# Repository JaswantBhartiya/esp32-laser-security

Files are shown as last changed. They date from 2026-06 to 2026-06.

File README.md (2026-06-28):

<div align="center">
  
Laser Security Sentinel Icon
  <br><br>
Typing Effect Headline

<br><br>

# 🛡️ ESP32 Multi-Bounce Laser Security System
<!-- Badges Section -->
<p align="center">
  
  
  
  
  
  
  
   
  
  
  
</p>

<h4>
    <a href="#demo">Demo</a>&nbsp;&nbsp;&nbsp;&nbsp;•&nbsp;&nbsp;&nbsp;&nbsp;
    <a href="#hardware">Hardware Design</a>&nbsp;&nbsp;&nbsp;&nbsp;•&nbsp;&nbsp;&nbsp;&nbsp;
    <a href="#mechanical">Mechanical Shroud</a>&nbsp;&nbsp;&nbsp;&nbsp;•&nbsp;&nbsp;&nbsp;&nbsp;
    <a href="#firmware">Firmware & Calibration</a>&nbsp;&nbsp;&nbsp;&nbsp;•&nbsp;&nbsp;&nbsp;&nbsp;
    <a href="https://github.com/JaswantBhartiya" target="_blank">Contact</a>
</h4>
</div>

<br>

A professional, budget-friendly embedded security system built around a custom PCB and the ESP32 DevKit V1. This project utilizes an optical multi-bounce laser path bounced across real glass mirrors to form a tight perimeter grid, monitored dynamically by an onboard Light Dependent Resistor (LDR).

<br><br>

---

## <span id="demo">🚀</span> Key Features & Demo

* **Wireless Perimeter Design:** The laser operates on its own isolated battery across the room, eliminating long, messy signal lines back to the controller.
* **Multi-Bounce Path:** Supports $650\text{nm}$ red or $532\text{nm}$ green lasers, holding a sharp focal point through 4 to 5 mirror reflections.
* **Auto Ambient Calibration:** Samples room light on boot to calculate a dynamic trigger threshold, preventing false alarms from day to night.
* **Dual-State LED Status:** Uses a Red-Green LED array (**Green** for Armed, **Red** for Tripped) mirrored on both the board and an external header.
* **Hardware Reset Button:** A debounced button on `GPIO 18` instantly clears the alarm, silences the buzzer, and re-arms the system.

<br>

### 🖥️ Live Web UI Dashboard
The system hosts a real-time responsive dashboard providing live telemetry, node statuses, and toggle configurations.

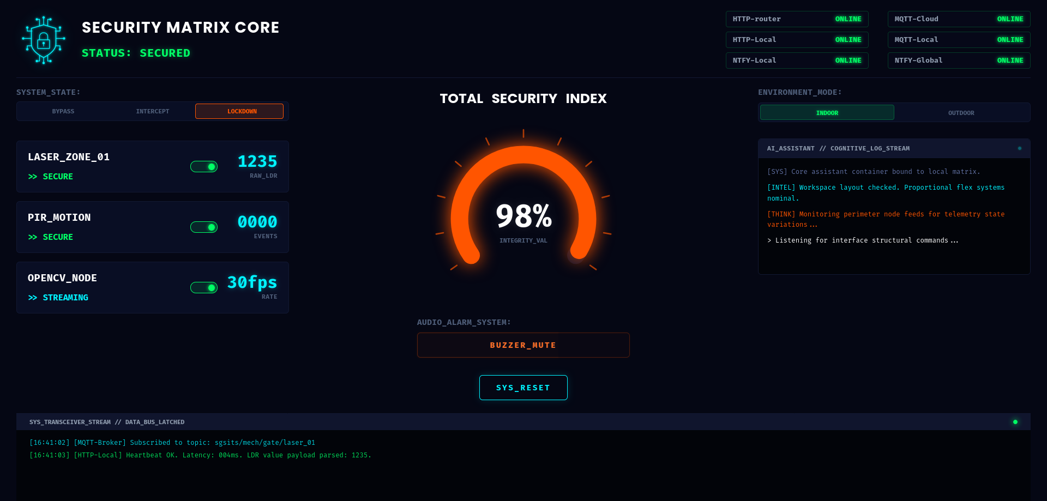
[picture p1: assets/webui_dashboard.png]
webui-dashboard


| Central Telemetry Instrumentation | Edge Sensor Matrix Nodes |
| :---: | :---: |
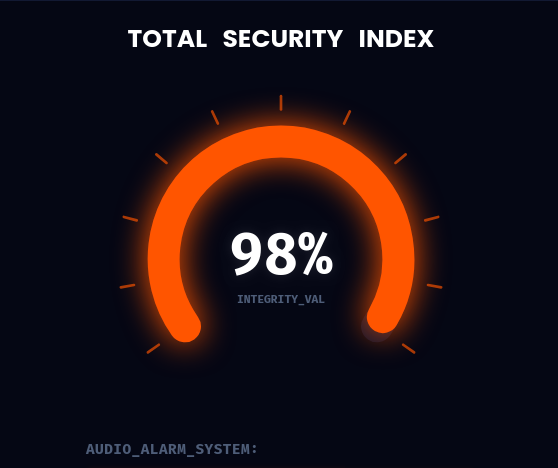
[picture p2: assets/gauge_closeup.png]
Radial Gauge
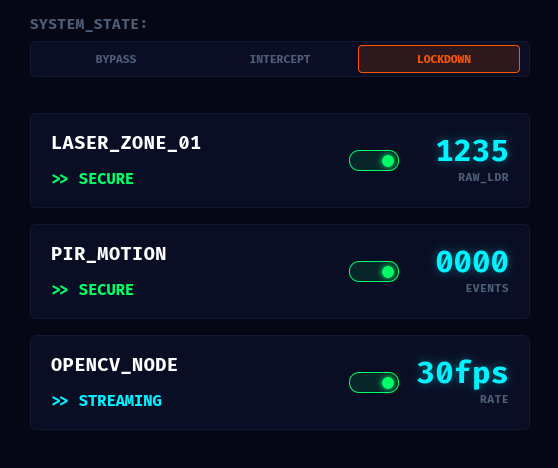
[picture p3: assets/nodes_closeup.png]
Sensor Status Toggles
|  |  |

#### 🌐 Robust 6-Way Connection Matrix
To guarantee fail-safe alerts and zero telemetry loss, the firmware maintains six independent network connections across local and global layers:
* **Wi-Fi Link Status:** Dual-channel monitoring covering your local gateway routing (`HTTP-Local`) and direct internet access (`HTTP-Router`).
* **MQTT Brokers:** Redundant pub/sub data streams routed concurrently to an offline network broker (`MQTT-Local`) and a remote cloud cluster (`MQTT-Cloud`).
* **Ntfy Push Alerts:** High-priority notification pipelines feeding instant breach logs via a self-hosted instance (`NTFY-Local`) and a global web server (`NTFY-Global`).

<br>

---

## <span id="hardware">🛠️</span> Hardware Design

### System Schematic
The circuit diagram maps out the ESP32 interface, sensor voltage dividers, and laser control lines for low-noise operation.

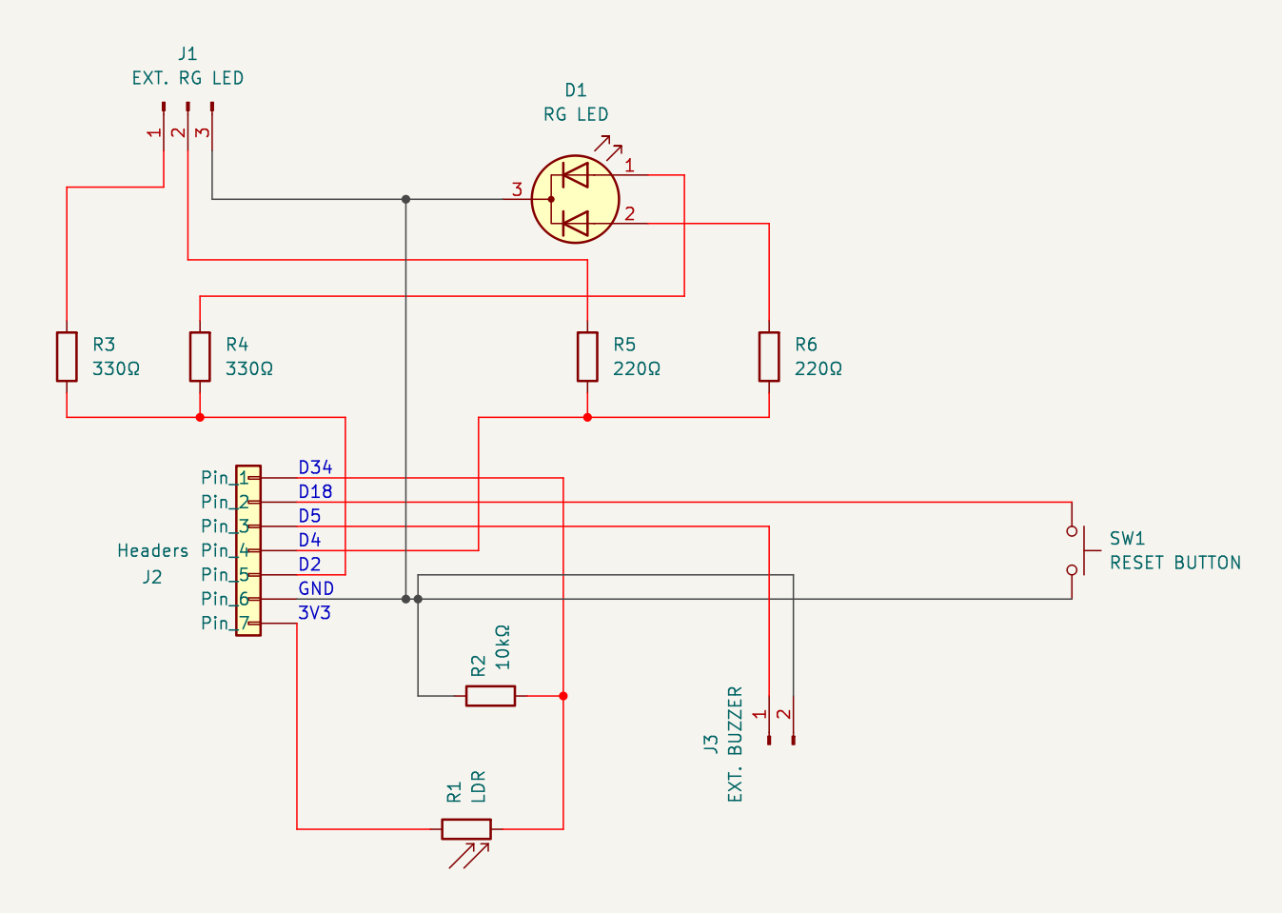
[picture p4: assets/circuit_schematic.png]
Circuit Schematic


<br>

### 📐 Electronics Layout (Raw KiCad PCB)
The custom board features a compact form factor, dedicated mounting holes, and clear silkscreen labeling.

| Front Layout | Back Layout |
| :---: | :---: |
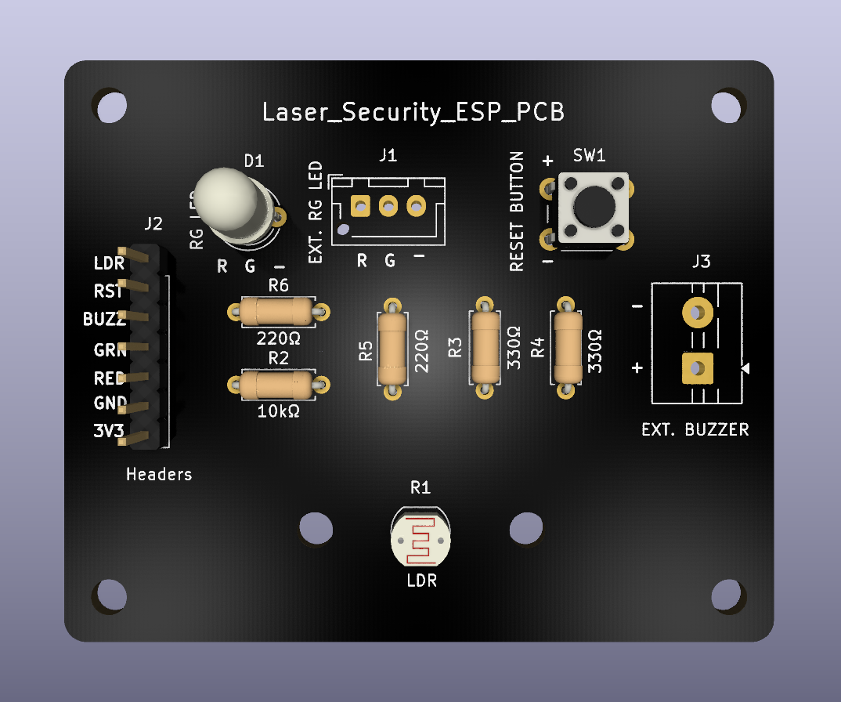
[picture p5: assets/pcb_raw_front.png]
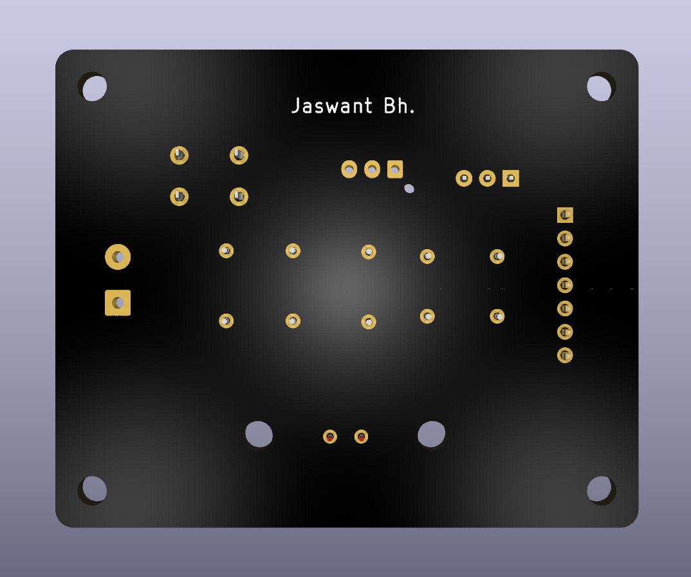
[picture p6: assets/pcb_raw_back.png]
|  |  |

<br>

### <span id="mechanical"></span>⚙️ Standalone Mechanical Mount
To achieve complete optical isolation and filter out ambient environmental light, a custom-molded mounting shroud was engineered.
<details> 
<summary><b>Click to Expand | Standalone Shroud Views</b></summary>

<br>

| Isometric View | Front View | Back View |
| :---: | :---: | :---: |
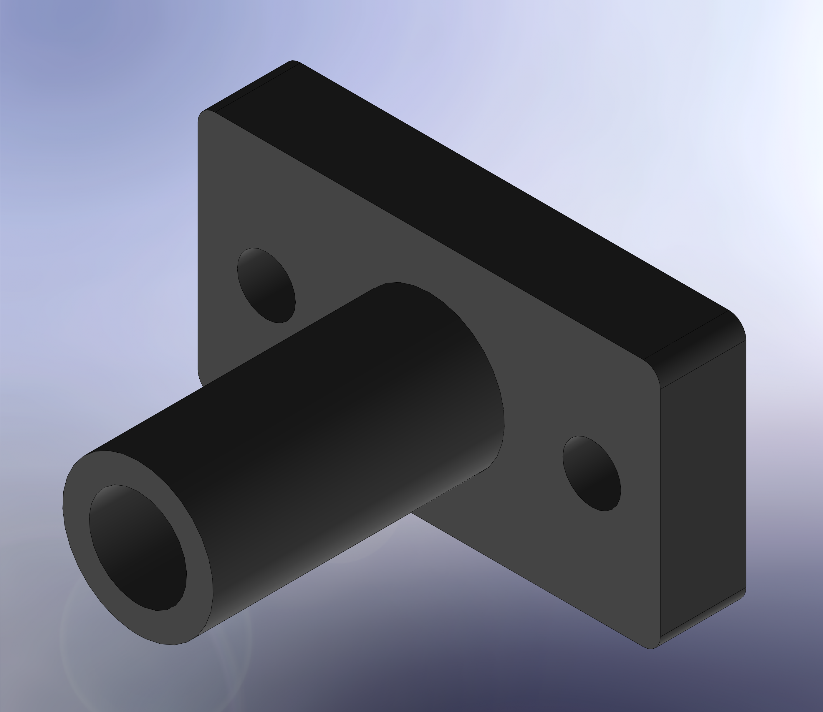
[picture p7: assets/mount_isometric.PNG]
Mount Front
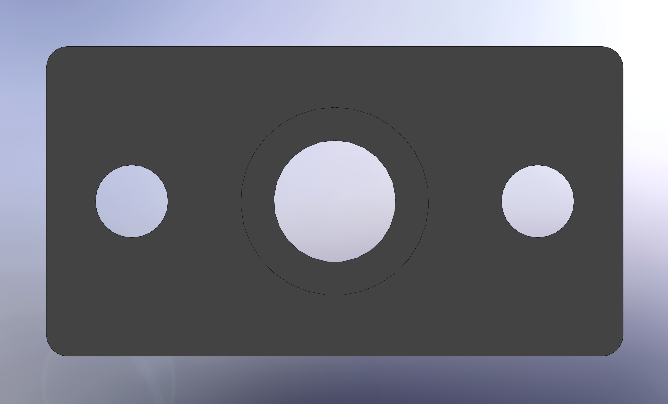
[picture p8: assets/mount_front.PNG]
Mount Top
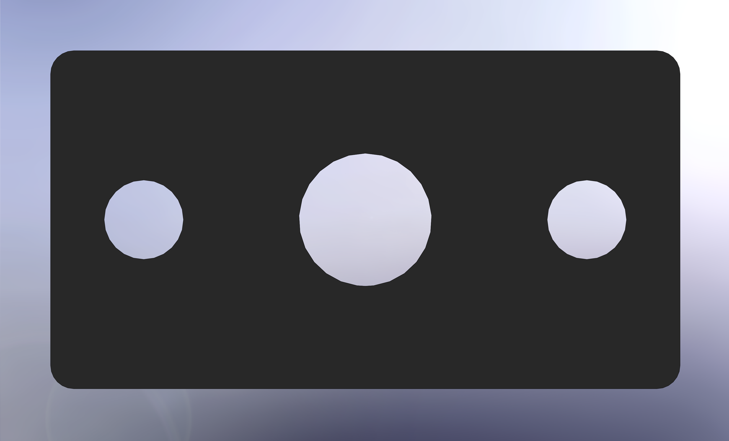
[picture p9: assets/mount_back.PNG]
Mount Bottom
|  |  |  |

#### 📐 Engineering Dimensions & Tolerances
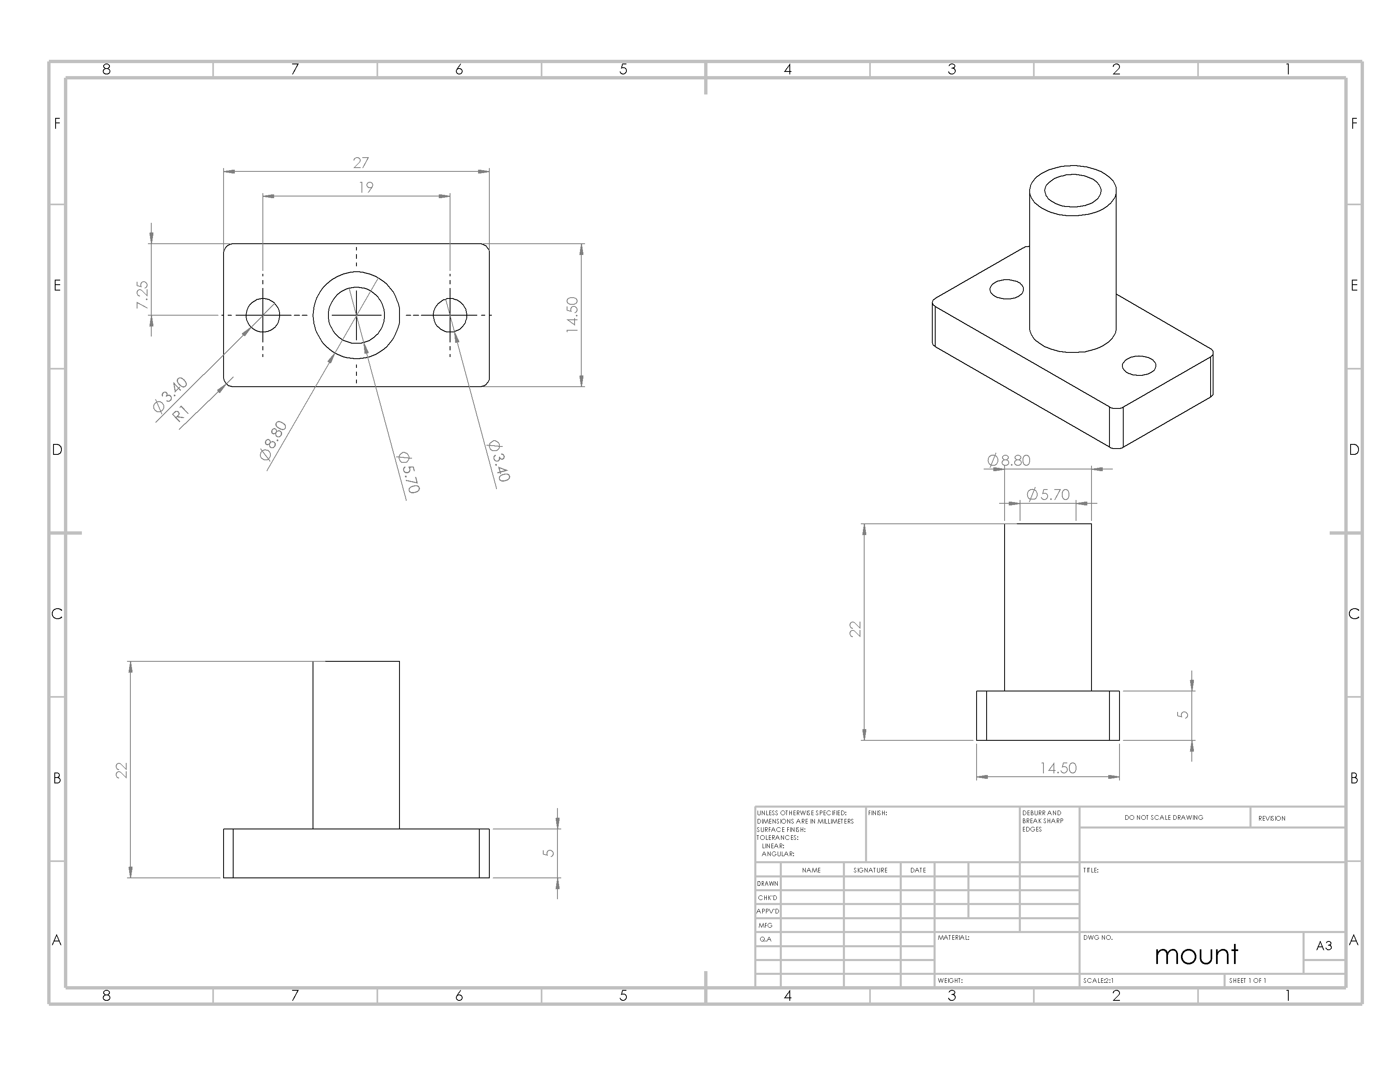
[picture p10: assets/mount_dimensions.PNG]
Mount Dimensions


**Design Specifications:**

* **Material:** Matte/Satin Dark Grey PLA (To absorb stray internal reflections)
* **Internal Diameter:** Uniform 5.7mm corridor (Provides a 0.5mm clearance cushion for hand-soldered LDR play and FDM printing shrinkage)
* **Fasteners:** Dual M3 clearance holes for flush mounting.

</details>

<br>

👉 **[Click here to view the interactive 3D Mount Model Natively on GitHub](./production/3d_printing/mount.STL)**

<br>

### 🤝 Fully Integrated Assembly
The combined views show the mechanical shroud assembly bolted directly onto the electronic control circuit board.

<div align="center">
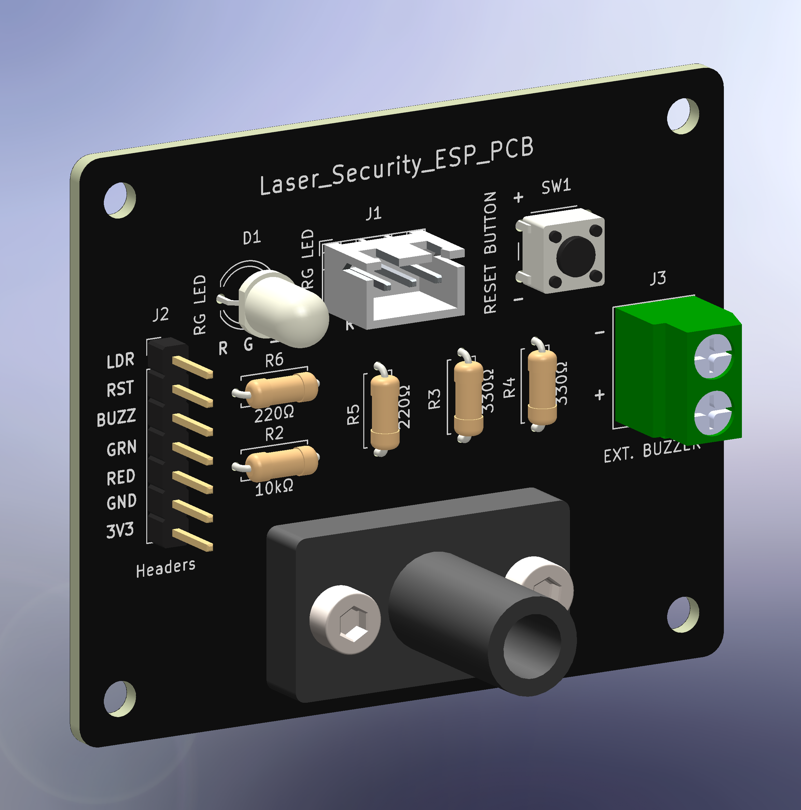
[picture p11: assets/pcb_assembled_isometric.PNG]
Integrated Isometric
       
</div>

<br>
       
| Assembly Top View | Assembly Solder Side View |
| :---: | :---: |
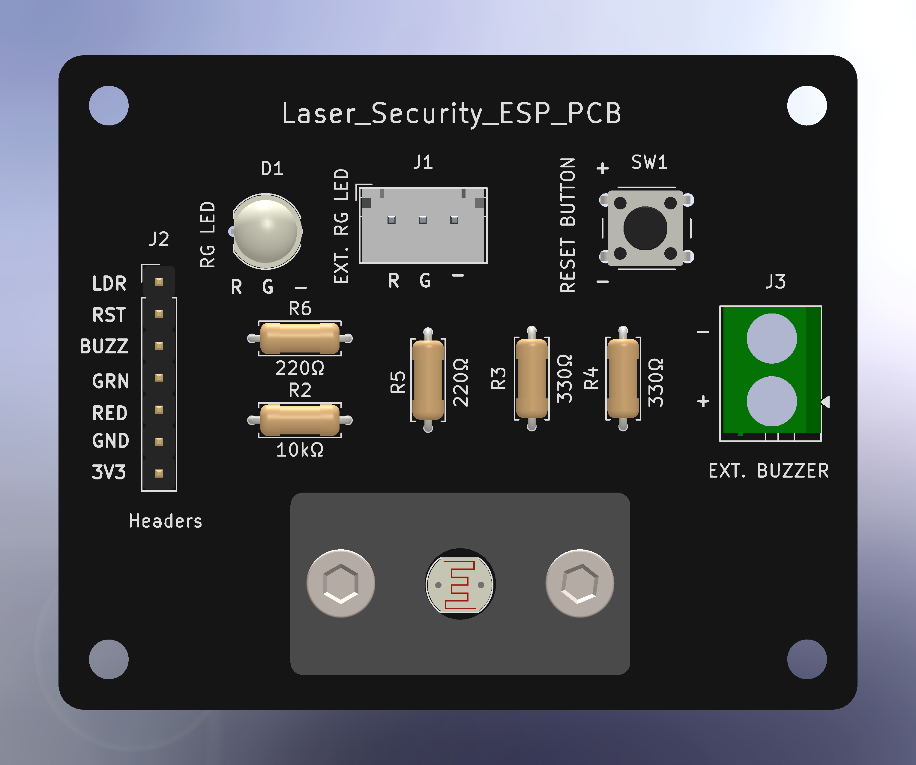
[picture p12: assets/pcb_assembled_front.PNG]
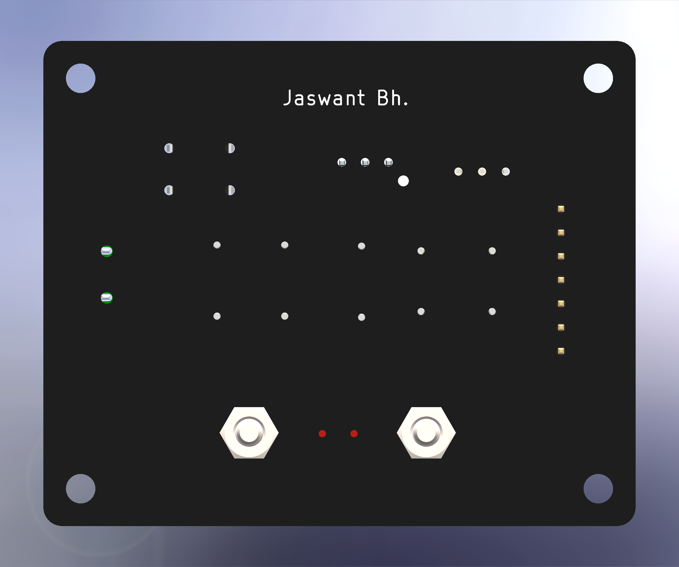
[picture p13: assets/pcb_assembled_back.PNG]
|  |  |

<br>

---

## 🔋 Power Setup

<details>
  
<summary><b>Click to Expand | Power Setup for two Paths</b></summary>

<br>

The system uses **two separate power paths** to stop electrical noise from the laser from messing with the ESP32 and sensors.

### ⚡ Path 1: ESP32 & Custom PCB
Powers the main controller and sensor board.

<div align="center">
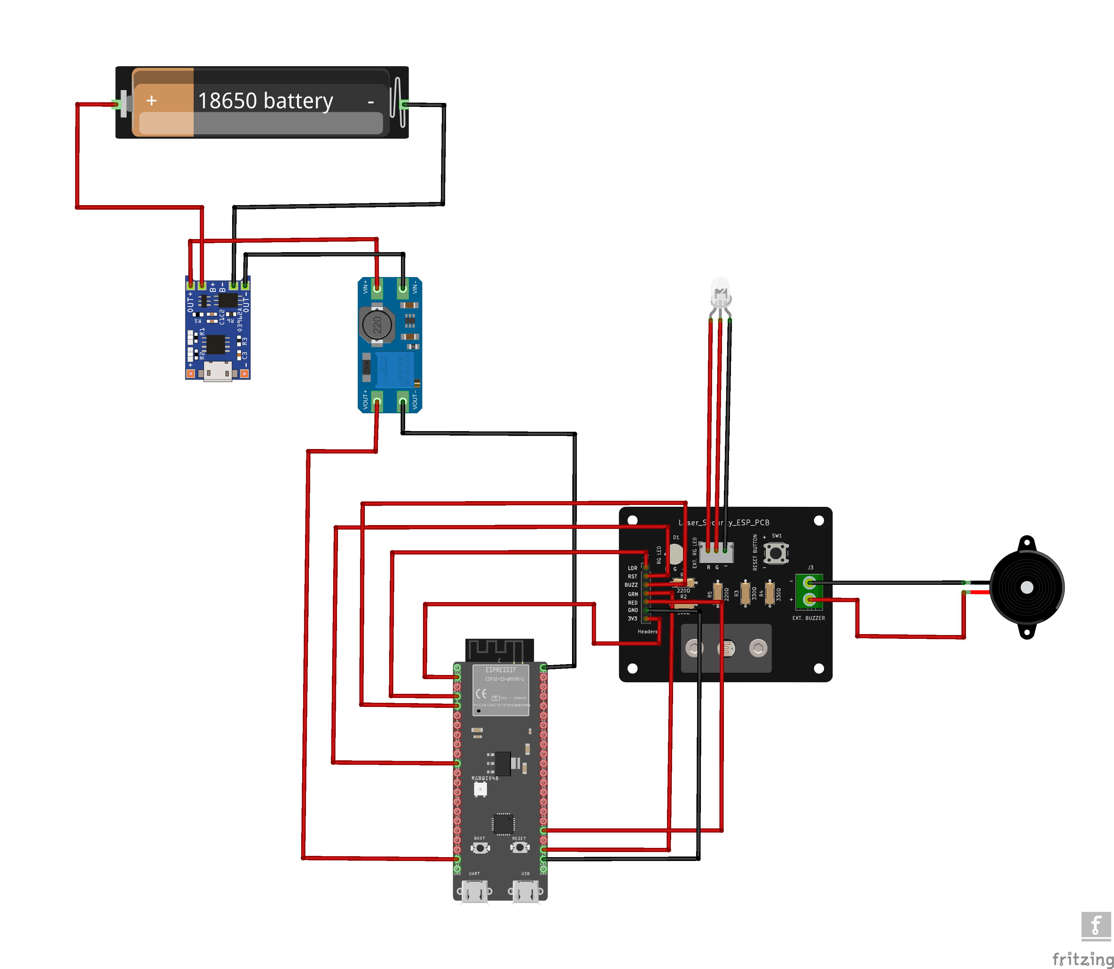
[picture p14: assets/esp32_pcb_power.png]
ESP32 Power Layout
       
</div>

<br>

* **Battery (18650)** ➔ **TP4056 Charger** (Safe charging)
* **TP4056 Output** ➔ **Boost Converter** (Steps up voltage)
* **Boost Converter (5V)** ➔ **ESP32 Pin (5V)** (Powers MCU)
* **ESP32 Pin (3.3V)** ➔ **Custom PCB (J2)** (Powers LDR & LED)

<br>

### 🔦 Path 2: Standalone Laser Transmitter Node
Powers the laser module independently with zero physical connection to the main board.

<div align="center">
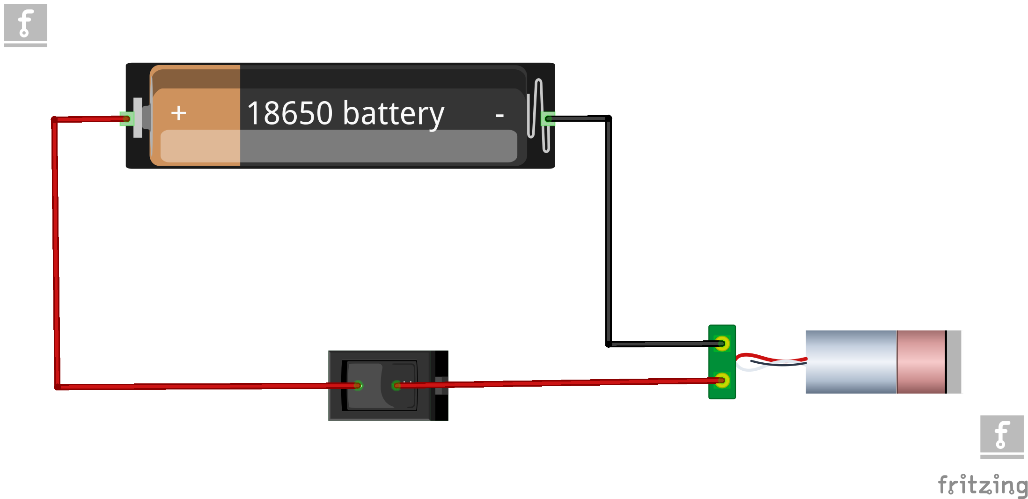
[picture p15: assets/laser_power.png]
Laser Power Layout
    
</div>

<br>

* **100% Isolated:** No shared wires or common ground loops with the ESP32-S3.
* **18650 Battery Powered:** Runs on its own 18650 cell (~3.7V) for maximum, long-lasting brightness.
* **Manual Switch Control:** Uses an inline rocker switch to completely cut power and save battery when off.

</details> 

<br>

---

## 📂 Repository Structure
``` yaml
      esp32-laser-security/
      ├── src/                             # 💻 Firmware Source Code (PlatformIO)
      │   ├── main.cpp                     #   └── Main security system logic
      │   └── testing/                     #   └── Isolated hardware testing scripts
      │       └── laser-connected-esp.cpp
      │
      ├── esp32-laser-security-pcb/        # 🛠️ KiCad Hardware Design Files
      │   ├── *.kicad_sch                  #   └── Circuit schematic
      │   └── *.kicad_pcb                  #   └── PCB routing layout
      │
      ├── production/                      # 📦 Manufacturing & 3D Printing Files
      │   ├── gerbers/                     #   └── PCB manufacturing files (Gerbers)
      │   ├── 3d_printing/                 #   └── 3D-printable mount shroud (.STL / .3MF)
      │   └── step_models/                 #   └── 3D CAD assembly model (.STEP)
      │
      ├── assets/                          # 🖼️ Documentation Media
      │   ├── circuit_schematic.png        #   └── Circuit diagram for README
      │   ├── pcb_raw_*.png/jpg            #   └── 3D images of unmounted PCB
      │   ├── mount_*.jpg                  #   └── 3D images of standalone plastic mount
      │   └── pcb_assembled_*.jpg          #   └── Photos of the final assembly
      │
      ├── platformio.ini                   # ⚙️ Project configuration & libraries
      └── README.md                        # 📖 Main project documentation guide
```
<br>

---

## 🛠️ Hardware Requirements

| Component | Quantity | Purpose |
| :--- | :--- | :--- |
| **ESP32-S3 DevKitC-1 N16R8** | 1 | Central processing unit & real-time monitoring engine |
| **SYD1230 650nm 5mW Red Laser Module** | 1 | Focusable transmitter node optimized for budget-friendly bouncing |
| **Light Dependent Resistor (LDR)** | 1 | High-sensitivity optical receiver |
| **SFM-27 Active Piezo Buzzer (Continuous Sound)** | 1 | 3–24V high-decibel audible indicator; allows the ESP32 to cleanly drive custom dual-frequency police siren sweeps without internal timing conflicts |
| **First-Surface Mirrors / HDD Platters** | 2–4 | Zero-ghosting high-reflectivity corner reflection nodes |
| **Metal Film Resistor (10 kΩ)** | 1 | Pull-down resistor for the analog voltage divider circuit |
| **Metal Film Resistor (330 Ω)** | 2 | Current-limiting protection resistors (e.g., for status LEDs) |
| **Metal Film Resistor (220 Ω)** | 2 | Current-limiting protection resistors (e.g., for buzzer power constraints) |
| **6x6x5mm Tactile Push Button Switch** | 1 | PCB-mount tactile switch for instant manual system reset or calibration |
| **7×1 Pin Male Berg Header (Straight, 10mm Height, 2.54mm Pitch)** | 1 | Breakout interface connector for peripheral GPIO programming/debugging pins |
| **XY126V-5.0-2P Green Screw Terminal Block (5mm Pitch, Through Hole)** | 1 | XINLAIYA 10A 300V power connector with wire protection for external main DC input |
| **3 Pin JST XH 2.5mm Top Entry Header (Straight Male & Female Pair)** | 1 | Polarity-keyed locking connector for secure LDR receiver wire routing |
| **Socket Head Cap Screw (M3x12)** | 2 | High-strength mechanical fasteners for enclosure or PCB corner mounting |
| **M3 Stainless Steel Hex Nut** | 2 | Matching rust-resistant hexagonal nuts to secure the M3 mounting screws safely |

<br>

---

## 🔌 Circuit Topology & Wiring

To achieve a clean optical baseline and prevent room lighting from flooding the sensor, the LDR must be housed inside an opaque, dark isolation tube pointed directly down the incoming laser path.

### Central Control Unit Pinout Mapping

```text
      +-----------------------------------------------------------------+
      |                    ESP32-S3 DevKitC-1 N16R8                     |
      +-----------------------------------------------------------------+
        | GPIO 4 (ADC) | <-------> Pin 1: LDR  (R1 Sensor Output Node)
        | GPIO 18       | <-------- Pin 2: RST  (Reset Push Button SW1)
        | GPIO 5        | --------> Pin 3: BUZZ (External Buzzer J3)
        | GPIO 19*      | --------> Pin 4: GRN  (Green LED Control Rail)
        | GPIO 21*      | --------> Pin 5: RED  (Red LED Control Rail)
        | GND           | --------> Pin 6: GND  (Common System Ground)
        | 3V3           | --------> Pin 7: 3V3  (System Power Input)

```
``` text
        +-----------------------------------------------------------------------------------+
        |                            EXTERNAL COMPONENT CONNECTIONS                         |
        +-----------------------------------------------------------------------------------+
        |                                                                                   |
        |  [ PCB Header J1 ] --------------------> Connects to EXTERNAL RG LED              |
        |     (EXT. RG LED)                         - Pin R: Red Indicator Anode            |
        |                                           - Pin G: Green Indicator Anode          |
        |                                           - Pin -: Common Ground Rail             |
        |                                                                                   |
        |  [ PCB Header J3 ] --------------------> Connects to EXTERNAL ACTIVE BUZZER       |
        |     (EXT. BUZZER)                         - Pin +: Positive Audio Signal Input    |
        |                                           - Pin -: Negative Ground Return         |
        |                                                                                   |
        +-----------------------------------------------------------------------------------+

```

### 3.3V Safe Voltage Divider Layout

```text
3V3 Rail -----[ LDR ]-----+-----> GPIO 34 (Analog Read Input)
                          |
                     [ 10kΩ Resistor ]
                          |
                         GND Rail
```
_Note: Powering the LDR network from the 3V3 rail protects the ESP32's 12-bit ADC pins from 5V over-voltage degradation._

<br>

---

## 💻 Software Configuration & Installation

This project is built using PlatformIO IDE inside VS Code for robust environment management and smaller, compiled binary footprints.
### Project Environment Configuration (platformio.ini)

```Ini, TOML

[env:esp32-s3-devkitc-1]
platform = espressif32
board = esp32-s3-devkitc-1
framework = arduino
monitor_speed = 115200

# Force the compiler to disable PSRAM tracking to prevent boot panics
build_flags = 
    -DBOARD_HAS_PSRAM=0
    -DARDUINO_USB_CDC_ON_BOOT=1

# Specify LittleFS partitioning layout
board_build.filesystem = littlefs

# Standard partition table for an 8MB Flash device (No PSRAM)
board_build.partitions = default_8MB.csv

lib_deps =
    esphome/ESPAsyncWebServer-esphome @ ^3.2.2
    knolleary/PubSubClient @ ^2.8

# Tell PlatformIO to compile everything in src, EXCEPT the testing folder
build_src_filter = +<*> -<testing/>

```
<br>

### Deployment Instructions

1. Clone this repository to your local workspace:
    ```Bash
    git clone https://github.com/JaswantBhartiya/esp32-laser-security.git
    ```
    
2. Open the project folder directly inside **Visual Studio Code** with the **PlatformIO** extension active.

3. Align your external laser node across your mirror grid so it hits the center of the LDR tube.

4. Click the **PlatformIO**: **Upload** arrow icon on the bottom status bar (or press (`Ctrl + Alt + U`) to compile and flash the firmware.

5. Open the **Serial Monitor** (`Ctrl + Alt + M`) at `115200` baud to watch the system run its initial calibration profiling.
<br><br>

---

## ⚙️ How System States Work

```text
  
           +------------------+
           | STATE_CALIBRATING| <-------- On Boot / User Reset
           +------------------+
                     |
                     v (Samples light & computes threshold)
           +------------------+
      +--->|   STATE_ARMED    |
      |    +------------------+
      |              |
      |              v (Beam broken for >50ms)
      |    +------------------+
      |    |  STATE_BREACHED  |
      |    +------------------+
      |              |
      +--------------+ (Reset Button Pressed)

```

* **Boot Calibration:** Samples the laser beam for 3 seconds to calculate a dynamic trigger threshold between direct laser light and ambient room light.
* **Active Guard:** Continuously samples the LDR. Requires the beam to be broken for over `50ms` to filter out false alarms from dust or bugs.
* **Breached Alert:** Plays a dual-tone siren sweep ($800\text{Hz}$ to $1300\text{Hz}$) on `GPIO 5` using non-blocking microsecond delays.
* **Hardware Reset:** Actively polls `GPIO 18`. Pressing the reset button instantly mutes the buzzer and recalibrates the system back to Armed mode.

<br>

---

## ⚙️ Calibration & Environment Tuning

### 🛠️ Quick Alignment Guide

1. **Align:** Aim the laser dot directly into the center of the LDR shroud.
2. **Calibrate:** Power on or reset the ESP32. Keep the laser path completely clear for the first **3 seconds**.
3. **Calculate:** The firmware auto-sets the trigger threshold using a simple median formula:

$$\text{Threshold} = \frac{\text{Laser Intensity} + \text{Ambient Light}}{2}$$

4. **Verify:** Block the beam with your hand to test that it instantly triggers the alarm.

<br>

### 🔍 Ambient Light Troubleshooting

| Issue | Root Cause | Quick Fix |
| :--- | :--- | :--- |
| **Instant alarm on boot** | Laser missed the LDR during calibration. | Re-align the laser and press the reset button to recalibrate. |
| **Beam broken, no alarm** | Side-glare or ambient room light is bleeding into the sensor. | Move away from windows or use a longer 3D-printed shroud to block ambient light. |
| **Siren flickers/jitters** | Laser dot is slightly misaligned or vibrating on the edge of the sensor. | Tighten your laser/mirror mounts to eliminate physical jitter. |

<br>

---

## 🚀 Hardware Evolution & Development
To see the complete multi-phase development timeline—including planned v2.0 hardware protection circuits, v3.0 wireless IoT feature tracking, and long-term mechanical upgrades—view the project's growth pipeline:

👉 **[View the Comprehensive Project Roadmap & Future Upgrades](./HARDWARE_ROADMAP.md)**

<br>

---

## 📄 License

This project is licensed under the MIT License - see the [`LICENSE`](./LICENSE) file for details.

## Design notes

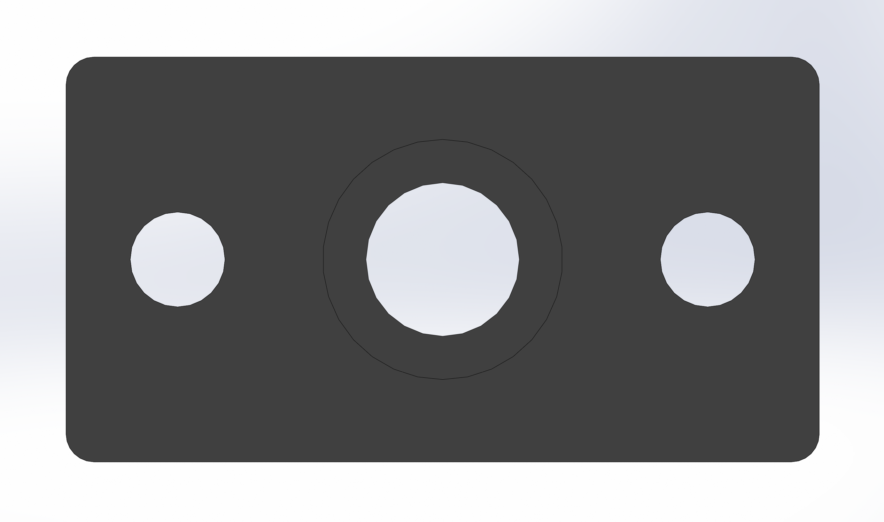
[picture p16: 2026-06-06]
assets/mount_top.PNG

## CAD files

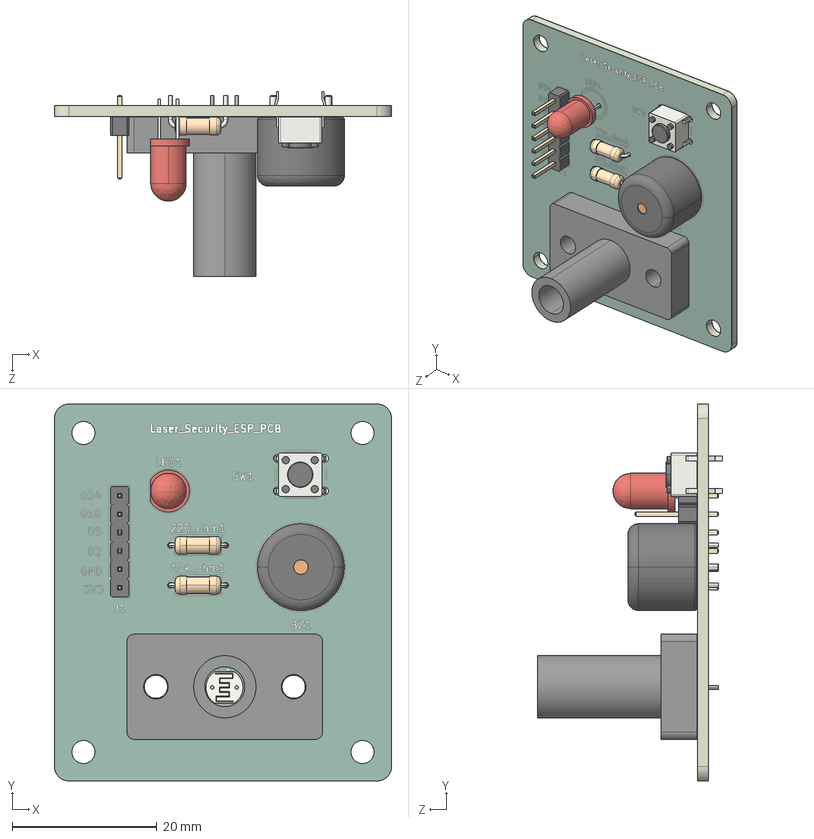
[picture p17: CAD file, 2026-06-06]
production/step_models/pcb_and_mount_assembly.STEP
46.5 x 52.0 x 25.5 mm
R_Axial_DIN0207_L63mm_D25mm_P762mm_Horizontal x 2
Buzzer_12x95RM76
PinHeader_1x06_P254mm_Vertical
R_LDR_5.1x4.3mm_P3.4mm_Vertical
LED_D5.0mm
SW_PUSH_6mm
esp32-laser-security_silkscreen
esp32-laser-security_soldermask
esp32-laser-security_soldermask_2
esp32-laser-security_PCB

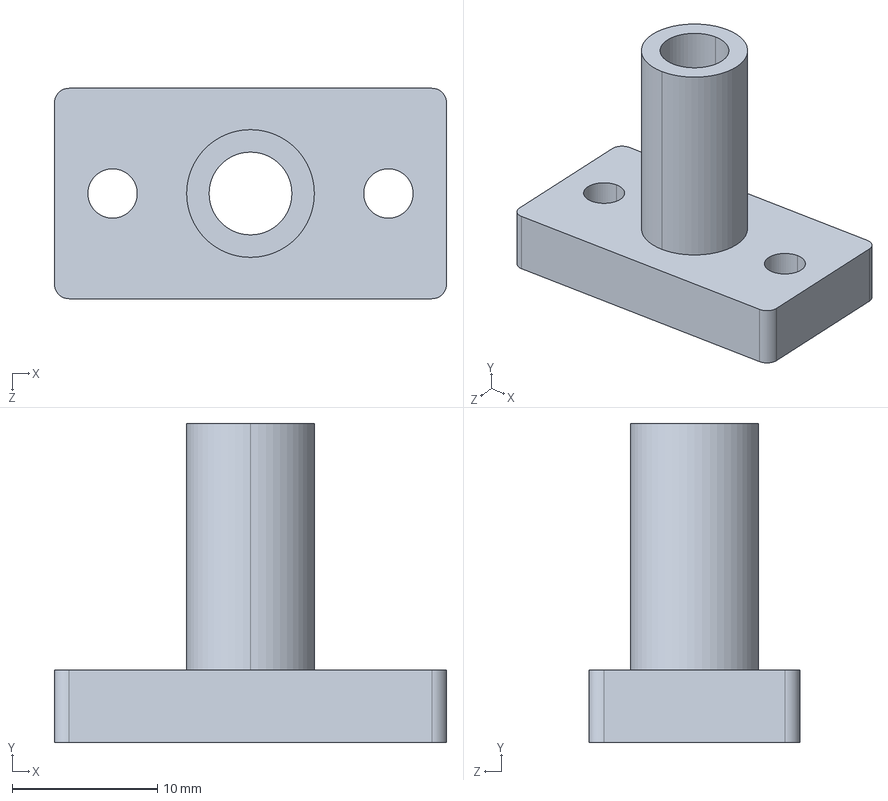
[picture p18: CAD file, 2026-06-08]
production/step_models/mount.STEP
27.0 x 22.0 x 14.5 mm

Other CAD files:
production/3d_printing/mount.STL

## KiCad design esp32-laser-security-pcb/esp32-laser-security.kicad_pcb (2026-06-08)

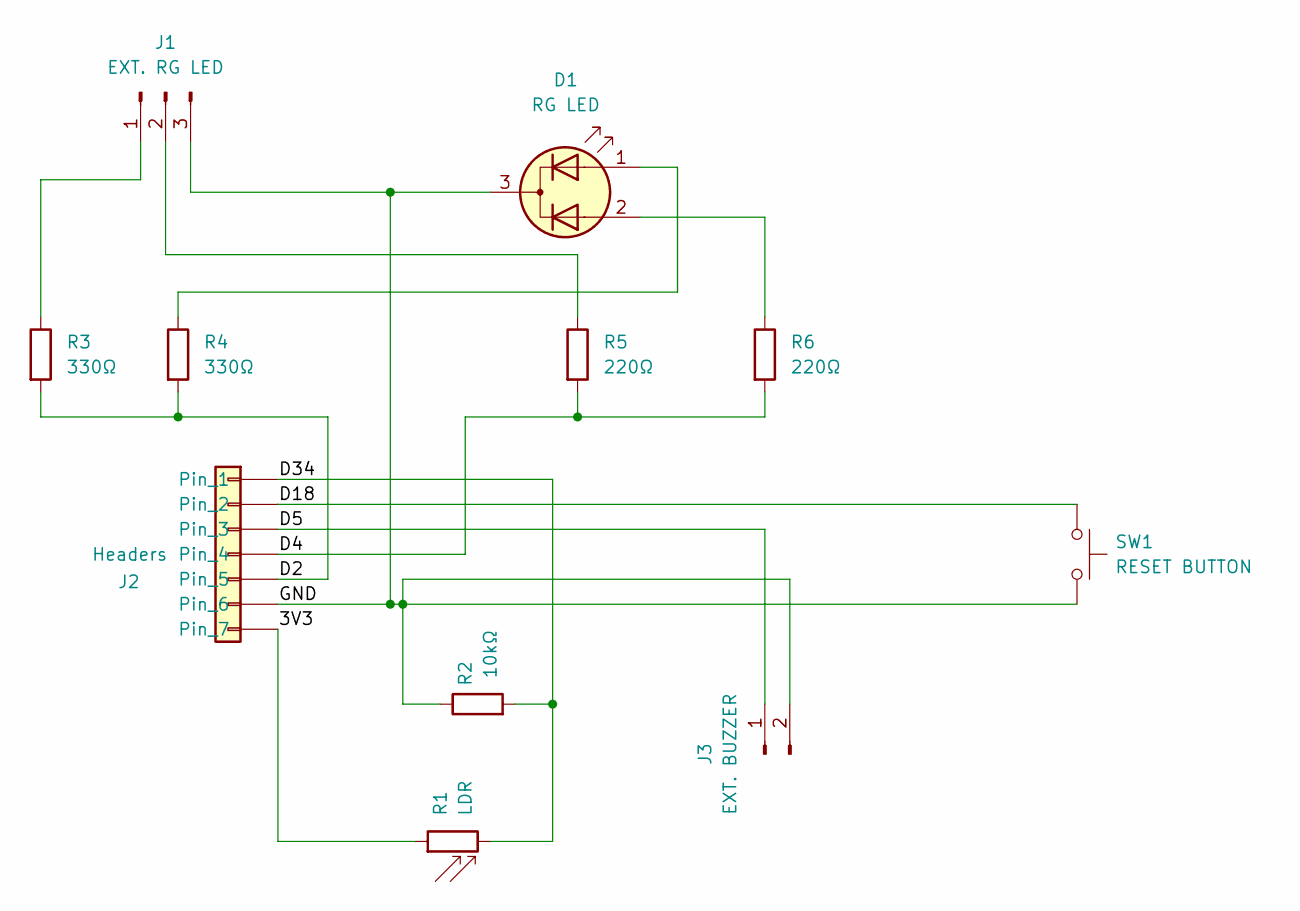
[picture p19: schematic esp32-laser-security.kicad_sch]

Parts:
D1: RG LED; LED_D5.0mm-3
J1: EXT. RG LED; JST_XH_B3B-XH-AM_1x03_P2.50mm_Vertical
J2: Headers; PinHeader_1x07_P2.54mm_Vertical
J3: EXT. BUZZER; TerminalBlock_MaiXu_MX126-5.0-02P_1x02_P5.00mm
R1: LDR; R_LDR_5.1x4.3mm_P3.4mm_Vertical
R2: 10kΩ; R_Axial_DIN0207_L6.3mm_D2.5mm_P7.62mm_Horizontal
R3, R4: 330Ω; R_Axial_DIN0207_L6.3mm_D2.5mm_P7.62mm_Horizontal
R5, R6: 220Ω; R_Axial_DIN0207_L6.3mm_D2.5mm_P7.62mm_Horizontal
SW1: RESET BUTTON; SW_PUSH_6mm

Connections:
/3V3: J2.7, R1.1
/D2: J2.5, R3.2, R4.2
/D4: J2.4, R5.2, R6.2
/D5: J2.3, J3.1
/D18: J2.2, SW1.1
/D34: J2.1, R1.2, R2.2
/GND: D1.3 (K), J1.3, J2.6, J3.2, R2.1, SW1.2
unnamed: D1.1 (A1), R4.1
unnamed: D1.2 (A2), R6.1
unnamed: J1.1, R3.1
unnamed: J1.2, R5.1

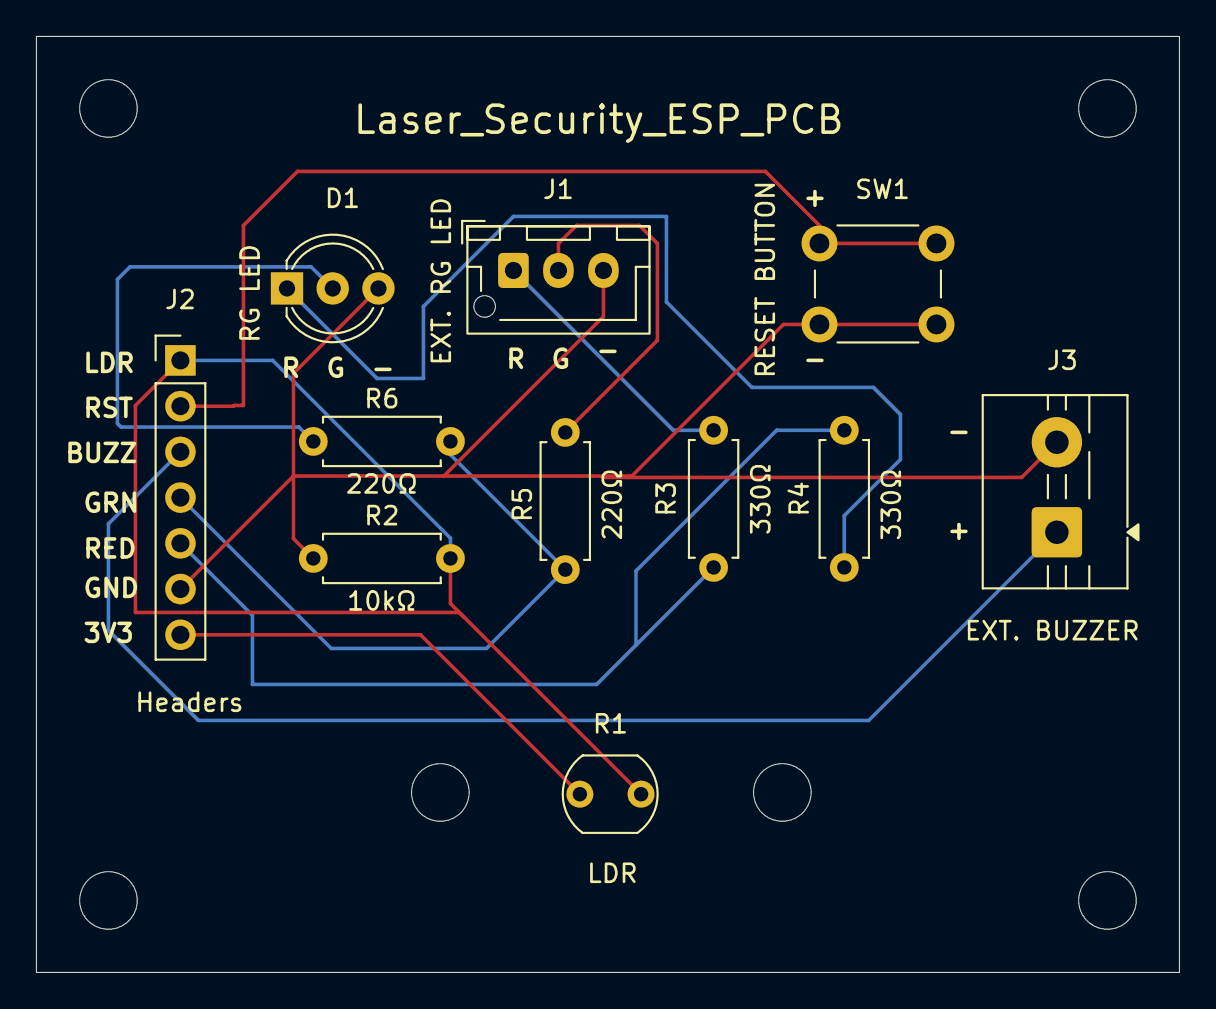
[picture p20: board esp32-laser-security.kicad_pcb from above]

Board: 2 copper layers, 63.5 x 52.0 mm, 11 parts (0 on the bottom side), 11 nets.

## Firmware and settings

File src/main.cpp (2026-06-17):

#include <WiFi.h>
#include <ESPAsyncWebServer.h>
#include <LittleFS.h>
#include <PubSubClient.h>

// =========================================================================
// 📡 NETWORK & HARDWARE CONFIGURATION PARAMETERS
// =========================================================================
const char* ap_ssid = "ESP32S3-Security-Hub";
const char* ap_pass = "secure1234";

const char* home_ssid = "WireShark-2.4Ghz"; 
const char* home_pass = "$p!D3y-PasS";    

const char* mqtt_server = "broker.hivemq.com";
const int mqtt_port = 1883; 
const char* mqtt_topic = "sgsits/mechanical/laserSecurity/alerts";

// =========================================================================
// 🎛️ OBJECT INSTANTIATIONS & GLOBAL SYSTEM VARIABLES
// =========================================================================
AsyncWebServer server(80);
WiFiClient espClient;
PubSubClient mqttClient(espClient);

// Shared Global Memory Layout Matrix
int globalLdrRaw = 450;
bool globalIsMuted = false;
String globalSystemMode = "NOTIFIER"; 
String globalLastAction = "RESET";

unsigned long lastMqttRetry = 0;
unsigned long lastHeartbeat = 0;

// =========================================================================
// 🔄 UNIFIED STATE BROADCAST COMPILER
// =========================================================================
void broadcastSystemStateMQTT() {
    if (WiFi.status() == WL_CONNECTED && mqttClient.connected()) {
        String payload = "{\"ldr_raw\":" + String(globalLdrRaw) + 
                         ",\"is_muted\":" + (globalIsMuted ? String("true") : String("false")) + 
                         ",\"system_mode\":\"" + globalSystemMode + "\"" +
                         ",\"last_action\":\"" + globalLastAction + "\"}";
                         
        mqttClient.publish(mqtt_topic, payload.c_str());
        Serial.println("[MQTT WAN] Dispatched synchronization packet: " + payload);
    }
}

void mqttCallback(char* topic, byte* payload, unsigned int length) {
    String message = "";
    for (unsigned int i = 0; i < length; i++) { message += (char)payload[i]; }
    Serial.println("[MQTT INCOMING] Cloud packet intercepted: " + message);

    // Strict string parsing rules to handle remote UI toggles smoothly
    if (message.indexOf("\"system_mode\":\"NOTIFIER\"") > 0) globalSystemMode = "NOTIFIER";
    else if (message.indexOf("\"system_mode\":\"ARMED\"") > 0) globalSystemMode = "ARMED";

    if (message.indexOf("\"is_muted\":true") > 0) globalIsMuted = true;
    else if (message.indexOf("\"is_muted\":false") > 0) globalIsMuted = false;

    if (message.indexOf("\"last_action\":\"BREACH\"") > 0) {
        globalLdrRaw = 3850;
        globalLastAction = "BREACH";
    } 
    else if (message.indexOf("\"last_action\":\"RESET\"") > 0) {
        globalLdrRaw = 450;
        globalLastAction = "RESET";
    } 
    else if (message.indexOf("\"last_action\":\"MUTE\"") > 0) {
        globalLastAction = "MUTE";
    }
}

void handleMqttReconnection() {
    // Only attempt MQTT operations if the background Wi-Fi link has successfully connected
    if (WiFi.status() == WL_CONNECTED && !mqttClient.connected()) {
        unsigned long now = millis();
        if (now - lastMqttRetry > 5000) { 
            lastMqttRetry = now;
            Serial.print("[MQTT LOG] Home router connected. Binding to HiveMQ broker matrix...");
            
            String clientId = "ESP32S3_Gateway_" + String(random(0, 9999));
            if (mqttClient.connect(clientId.c_str())) {
                Serial.println(" CONNECTED!");
                mqttClient.subscribe(mqtt_topic);
                broadcastSystemStateMQTT();
            } else {
                Serial.print(" FAILED, rc=");
                Serial.println(mqttClient.state());
            }
        }
    }
}

// =========================================================================
// 🚀 CORE SETUP INITIALIZATION INTERFACE (NON-BLOCKING)
// =========================================================================
void setup() {
    Serial.begin(115200);
    delay(1000); 
    
    Serial.println("\n==============================================");
    Serial.println("[SYSTEM CORE] INITIALIZING ASYNCHRONOUS NETWORK LAYER...");
    Serial.println("==============================================");

    if (!LittleFS.begin()) {
        Serial.println("[ERROR] LittleFS Mounting Failure! Process halted.");
        return;
    }

    // Set dual-mode station + access point configurations
    WiFi.mode(WIFI_AP_STA);

    // 1. Spawn Local Hotspot Instantly (Zero Waiting Time)
    WiFi.softAP(ap_ssid, ap_pass);
    Serial.print("[AP] Local Sentinel Portal Spawned. Gateway IP: ");
    Serial.println(WiFi.softAPIP());

    // 2. Bind all Async Web Server endpoints immediately 
    // This ensures 192.168.4.1 works instantly even if there's no router nearby!
    server.on("/", HTTP_GET, [](AsyncWebServerRequest *request){
        request->send(LittleFS, "/index.html", "text/html");
    });
    server.on("/style.css", HTTP_GET, [](AsyncWebServerRequest *request){
        request->send(LittleFS, "/style.css", "text/css");
    });
    server.on("/script.js", HTTP_GET, [](AsyncWebServerRequest *request){
        request->send(LittleFS, "/script.js", "application/javascript");
    });

    server.on("/api/status", HTTP_GET, [](AsyncWebServerRequest *request) {
        String jsonResponse = "{\"ldr_raw\":" + String(globalLdrRaw) + 
                              ",\"is_muted\":" + (globalIsMuted ? String("true") : String("false")) + 
                              ",\"system_mode\":\"" + globalSystemMode + "\"" +
                              ",\"last_action\":\"" + globalLastAction + "\"}";
        request->send(200, "application/json", jsonResponse);
    });

    server.on("/api/action", HTTP_GET, [](AsyncWebServerRequest *request) {
        if (request->hasParam("cmd")) {
            String command = request->getParam("cmd")->value();
            
            if (command == "mode_notifier") globalSystemMode = "NOTIFIER";
            else if (command == "mode_armed") globalSystemMode = "ARMED";
            else if (command == "sim_breach") {
                globalLdrRaw = 3850;
                globalIsMuted = false;
                globalLastAction = "BREACH";
            } 
            else if (command == "reset") {
                globalLdrRaw = 450;
                globalIsMuted = false;
                globalLastAction = "RESET";
            } 
            else if (command == "mute") {
                globalIsMuted = !globalIsMuted; // Toggles mute state cleanly
                globalLastAction = "MUTE";
            }
            
            broadcastSystemStateMQTT(); 
            request->send(200, "text/plain", "ACK");
        } else {
            request->send(400, "text/plain", "BAD REQUEST");
        }
    });

    server.begin();
    Serial.println("[SYSTEM CORE] Local Server Engine Activated on Port 80.");

    // 3. Initiate background handshake with home router
    Serial.print("[STA] Registering background connection request to: ");
    Serial.println(home_ssid);
    WiFi.begin(home_ssid, home_pass); 
    
    mqttClient.setServer(mqtt_server, mqtt_port);
    mqttClient.setCallback(mqttCallback);
}

// =========================================================================
// 🔄 REAL-TIME MAIN PROCESS MAINTENANCE LOOP
// =========================================================================
void loop() {
    // Check connection status and manage the MQTT subscription state completely in the background
    if (WiFi.status() == WL_CONNECTED) {
        handleMqttReconnection();
        mqttClient.loop();
    }

    // Low Frequency Background Telemetry Sync Loop
    unsigned long currentMillis = millis();
    if (currentMillis - lastHeartbeat > 4000) {
        lastHeartbeat = currentMillis;
        if (WiFi.status() == WL_CONNECTED && mqttClient.connected()) {
            broadcastSystemStateMQTT();
        }
    }

    // Your physical LDR analog acquisition hook layout maps down here later (analogRead(4))...
}

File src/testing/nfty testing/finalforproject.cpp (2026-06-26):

// V_0.3
// Topic: Final code that will be add to final code of this project
// Discription: Final code that will be add to final code of this project

#include <WiFi.h>
#include <HTTPClient.h>

// ======================== CONFIGURATION ========================
// 1. Home Router Configuration (Online Cloud Mode)
const char* routerSSID     = "YOUR_HOME_ROUTER_SSID";
const char* routerPASSWORD = "YOUR_HOME_ROUTER_PASSWORD";
const char* cloudNtfyUrl   = "https://ntfy.sh/local_laser_security_alarm";

// 2. Phone Hotspot Configuration (Open Network - No Password)
const char* hotspotSSID     = "AndroidAP_3211"; 
const char* hotspotPASSWORD = ""; // Empty string for unsecured hotspot
const char* localNtfyUrl    = "http://192.168.52.85:8080/local_laser_security_alarm";
// ===============================================================

// Global string to hold the automatically selected endpoint target
const char* activeNtfyUrl = ""; 

// Optimized function to push notifications out
void sendNtfyAlert(String message, String title, String priority, String tags) {
    if (WiFi.status() == WL_CONNECTED) {
        HTTPClient http;
        
        Serial.print("[ntfy] Routing alert to: ");
        Serial.println(activeNtfyUrl);
        
        http.begin(activeNtfyUrl);
        
        // Setup ntfy formatting metadata headers
        http.addHeader("Title", title);
        http.addHeader("Priority", priority); // 1 = Min, 5 = Max (Urgent)
        http.addHeader("Tags", tags);           // Notification Emojis
        
        int httpResponseCode = http.POST(message);
        
        if (httpResponseCode > 0) {
            Serial.printf("[ntfy] Alert delivered. Server Response Code: %d\n", httpResponseCode);
        } else {
            Serial.printf("[ntfy] Network post failed: %s\n", http.errorToString(httpResponseCode).c_str());
        }
        http.end();
    } else {
        Serial.println("[ntfy] Broadcast blocked: WiFi link is dead.");
    }
}

void setup() {
    Serial.begin(115200);
    delay(2000);
    
    Serial.println("\n==================================================");
    Serial.println("  🔒 LASER SECURITY ALARM - TRANSMITTER MODULE   ");
    Serial.println("==================================================");

    // Phase 1: Try targeting your Home Router network
    Serial.printf("\n[1/2] Scanning for Home Router: %s...\n", routerSSID);
    WiFi.begin(routerSSID, routerPASSWORD);
    
    int counter = 0;
    while (WiFi.status() != WL_CONNECTED && counter < 16) { 
        delay(500);
        Serial.print(".");
        counter++;
    }

    // Phase 2: Handle Route Validation or Hotspot Fallback
    if (WiFi.status() == WL_CONNECTED) {
        Serial.println("\n[Network] Connected to Home Router (Cloud Mode active).");
        activeNtfyUrl = cloudNtfyUrl; 
    } 
    else {
        Serial.println("\n[Network] Router offline. Pivoting to local backup routing...");
        WiFi.disconnect();
        
        Serial.printf("[2/2] Linking to Open Phone Hotspot: %s...\n", hotspotSSID);
        WiFi.begin(hotspotSSID); // Instantiates connection to unsecured network
        
        counter = 0;
        while (WiFi.status() != WL_CONNECTED && counter < 16) {
            delay(500);
            Serial.print(".");
            counter++;
        }
        
        if (WiFi.status() == WL_CONNECTED) {
            Serial.println("\n[Network] Connected to Phone Hotspot (Local Docker Mode active).");
            activeNtfyUrl = localNtfyUrl; 
        } else {
            Serial.println("\n[Network] CRITICAL ERROR: Transmitter could not establish any network profile.");
        }
    }

    // Send a boot greeting to your phone app/dashboard to confirm transmission works
    if (WiFi.status() == WL_CONNECTED) {
        Serial.print("[Network] Assigned Local IP: ");
        Serial.println(WiFi.localIP());
        
        Serial.println("\n👉 READY! Type a message in Serial Monitor and press Enter to transmit.");
        Serial.println("==================================================\n");

        sendNtfyAlert(
            "Transmitter Node initialized and standing by.", 
            "System Online", 
            "3", 
            "shield,white_check_mark"
        );
    }
}

void loop() {
    // Read from Serial Monitor so you can still manually trigger test alerts
    if (Serial.available() > 0) {
        String outgoingMessage = Serial.readStringUntil('\n');
        outgoingMessage.trim(); 
        
        if (outgoingMessage.length() > 0) {
            Serial.printf("[Local Command] Triggering transmission: \"%s\"\n", outgoingMessage.c_str());
            
            // Send the serial message text straight to your phone
            sendNtfyAlert(outgoingMessage, "Manual Console Alert", "4", "warning,bell");
        }
    }
}

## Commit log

2026-06-04 Initial commit: Streamlined independent laser architecture with jumper reset
    [main.cpp]
2026-06-04 Initialize README with project details and setup
    Added detailed project documentation for the Independent Long-Range Multi-Bounce Laser Security System, including features, hardware requirements, circuit topology, and software configuration.
2026-06-04 Added Kicad Schematic & PCB Design
    [esp32-laser-security-B_Cu.gbr, esp32-laser-security-B_Mask.gbr, esp32-laser-security-B_Paste.gbr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]
2026-06-04 changed pcb folder name
    [esp32-laser-security-B_Cu.gbr, esp32-laser-security-B_Mask.gbr, esp32-laser-security-B_Paste.gbr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]
2026-06-05 Updated pcb design and add schematic and 3D PCB render images for laser security board
    [esp32-laser-security-B_Cu.gbr, esp32-laser-security-B_Mask.gbr, esp32-laser-security-B_Paste.gbr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]
2026-06-05 removed unnecessary old files
    [esp32-laser-security-B_Cu.gbr, esp32-laser-security-B_Mask.gbr, esp32-laser-security-B_Paste.gbr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]
2026-06-05 added gerber files
    [esp32-laser-security-B_Cu.gbr, esp32-laser-security-B_Mask.gbr, esp32-laser-security-B_Paste.gbr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]
2026-06-06 added mount & updated pcb
    [.step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]
2026-06-06 Revise README for hardware design details and images
    Updated hardware design section with new PCB and mount images, and improved layout descriptions.
2026-06-06 Add system schematic to README
    Added a section for the system schematic with a diagram.
2026-06-06 added mount dimension sheet
2026-06-08 updated pcb
    [.step, esp32-laser-security.kicad_pcb, esp32-laser-security.kicad_sch]
2026-06-08 updated pcb schematic and gerber files for industry
    [esp32-laser-security.kicad_pcb, esp32-laser-security.kicad_sch]
2026-06-08 Revise PCB layout presentation in README
    Updated PCB layout images and enhanced formatting for clarity.
2026-06-08 updated mount files
    [mount.STEP]
2026-06-09 Add hardware hardening and optimization roadmap
    Document hardware modifications for the Laser Security ESP PCB to enhance reliability and performance in room-scale deployments, addressing vulnerabilities and implementing protective measures.
2026-06-09 Expand hardware roadmap with mechanical design details
    Added detailed sections on mechanical mounts and enclosure design for future revisions, including micro-adjustable mirror alignment mounts, decentralized external LED panels, and high-acoustic external buzzer housing.
2026-06-09 Revise Active Piezo Buzzer description in README
    Updated the description of the Active Piezo Buzzer to specify its continuous sound capability and voltage range.
2026-06-10 Add HTML5, CSS3, JavaScript, and ESP32-S3 badges
2026-06-10 Add .gitattributes to track frontend files
2026-06-11 Update internal diameter specification to 5.7mm
2026-06-12 Update ESP32 badge in README
2026-06-18 added powering pcb and esp section
2026-06-18 Update README with laser transmitter path
2026-06-18 added fritzing project with parts
    [esp32-laser-security-project.fzz]
2026-06-18 Clean up README by removing esp32dev config
    Removed commented configuration for esp32dev environment.
2026-06-20 added laser power suply fritzing project
    [laser-power-supply.fzz]
2026-06-26 Enhance README with power setup details
    Added detailed power setup section with two paths for ESP32 and sensors.

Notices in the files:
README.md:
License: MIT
